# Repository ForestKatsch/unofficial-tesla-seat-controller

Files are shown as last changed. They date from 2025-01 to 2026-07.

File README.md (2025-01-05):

# (unofficial) Tesla seat controller

This project contains everything necessary to build an Arduino shield that reads the seat controls and drives the seat motors and ventilation fans.

## Why?

I built a simracing rig, and I discovered that used Tesla seats in good condition were around the same price as purpose-built simracing seats, and are much more comfortable to boot. The only problem is that they're electrically actuated and can't be manually adjusted.

## How?

- [**Instructions**](docs/instructions.md) (start here)
- [Switchpack reverse-engineering](docs/switchpack.md)

## Changelog

| date | change |
| --- | --- |
| 2025.01.04 | documentation consolidation and prep work for proto1 |
| 2024.08.18 | proto0 / validation |

## References and sources

- [Dan Simma's video](https://www.youtube.com/watch?v=71O_Hcep4HI) convinced me this project was doable
- [Tesla's Model S electrical schematics](https://service.tesla.com/docs/ModelS/ElectricalReference/prog-54/interactive/html/index.html?page=62&) made it easy to find out which wires went where
- [A Delta PWM fan, very similar to the ventilation fans in the seat](https://www.delta-fan.com/applications/automotive/BFB1012HD-04D4L.html)

## License

TODO

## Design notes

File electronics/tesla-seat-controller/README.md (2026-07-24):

# Standalone Tesla seat controller

STM32G0-based controller for four seat motors, two ventilation fans, and the seat switchpack. Input is a regulated 12 V Mean Well power supply; record the exact model before system testing.

## Design status

The schematic passes ERC and the automated MCU pin-contract tests. The DRV8262s use KiCad's official top-PowerPAD DDV footprint:

`Package_SO:HTSSOP-44_6.1x14mm_P0.635mm_TopEP4.14x7.01mm`

Do not substitute the bottom-PowerPAD DDW footprint. The DDV thermal pad is on top and requires a heatsink for sustained high current.

## PCB requirements

- Put each driver's 10 nF VM capacitors directly at its VM/PGND pin groups.
- Put the VCP, CPH/CPL, DVDD, and VCC capacitors directly at their pins.
- Give both drivers short, wide, comparable +12 V and ground paths; do not feed one through the other.
- Preserve top-side clearance and mounting support for both DRV8262 heatsinks.
- Route motor and input current paths for the fused 10 A system current plus short peaks.
- Clearly label motor outputs A/B/C/D on silkscreen. XT30 polarity marks are not fixed electrical polarity on reversible motor outputs.
- Run DRC and a separate PCB audit before fabrication.

## Firmware safety contract

- DRV8262 hardware current regulation is about 14.6 A nominal; expected motor stall current is about 8 A.
- Monitor IPROPI and stop a motor when an 8 A-class stall persists beyond the chosen timeout.
- Use PWM-mode `00` to coast when stopping. Ramp down before reversing; do not reverse directly at full duty. This limits regeneration into the Mean Well supply.
- Treat nFAULT as latched: clear a fault with the datasheet-defined nSLEEP reset sequence.
- Fan outputs are open-drain and inverted. The Delta reference fan expects approximately 100 Hz PWM and stops near both duty-cycle extremes; validate against the actual seat fans.

## Validation

Run from the repository root:

```sh
kicad-cli sch erc --severity-all --format report \
  --output /tmp/tesla-seat-controller-erc.rpt \
  electronics/tesla-seat-controller/tesla-seat-controller.kicad_sch

python3 tests/test_pinmap.py
```

Before powering motors, verify the exact Mean Well model can supply the expected startup current. During first hardware tests, scope +12 V while stopping and reversing a loaded motor; add a braking clamp only if the rail rises excessively or the supply trips.

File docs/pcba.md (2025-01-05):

# PCB Assembly

The seat controller PCB is designed in KiCAD version 8.

TODO

# BOM

| Part | Quantity |
| --- | --- |
| [3-pin 2.54mm male header](https://a.co/d/1hqvut4) | 2x |
| [4-pin 2.54mm male header ](https://a.co/d/1hqvut4) | 1x |
| [XT30 horizontal male through-hole](https://a.co/d/ecAGn9J)  | 1x |
| [2-pin 5mm screw terminal connector](https://a.co/d/eVUlu4d) | 1x |
| 0805 100nF capacitor | 3x |
| 0805 1k resistor | 3x |

You'll also need the four primary Arduino headers (no need for the two 2x3 pin headers). I recommend using [male pin headers](https://a.co/d/1hqvut4) mounted beneath the board to avoid physical contact with components on the motor driver shield.

| Part | Quantity |
| --- | --- |
| 10-pin 2.54mm male header | 1x |
| 8-pin 2.54mm male header  | 2x |
| 6-pin 2.54mm male header  | 1x |

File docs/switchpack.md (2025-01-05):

# Switchpack

The Tesla seat switchpack is the collection of controls on the side of the seat. There are three physical controls, connected via a four-wire harness.

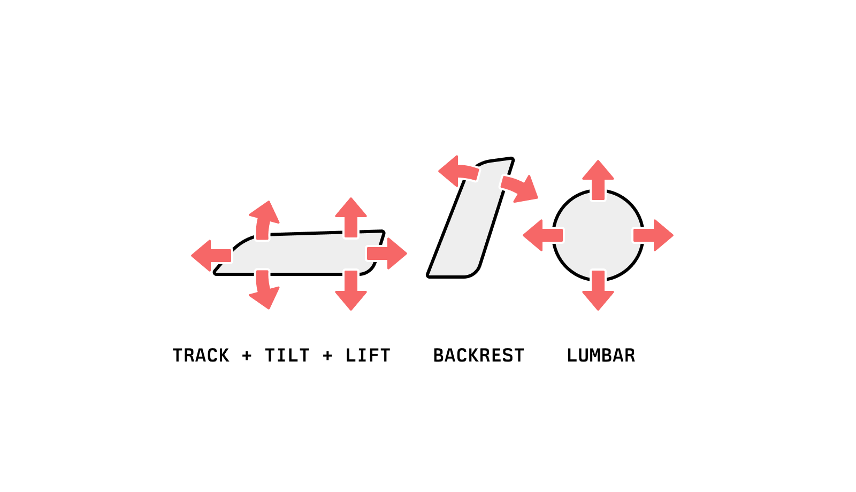
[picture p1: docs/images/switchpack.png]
The layout of the seat control switchpack, with a track + tilt + lift control at the front, a backrest lever behind it, and finally a four-way lumbar d-pad


Electrically, the switchpack interface has three signal wires and one ground line. When actuated, the switches assigned to each line vary the resistance of their corresponding wire.

| Numeric Index | Resistance Ω | Backrest + Track | Tilt + Lift | Lumbar |
| --- | ---: | --- | --- | --- |
| | 1.355 | | |
| #0 | 1.179 | Backrest Fore | Tilt Up | Fore |
| #1 | 0.774 | Backrest Aft | Tilt Down | Aft |
| #2 | 1.010 | Track Fore | Lift Up | Up |
| #3 | 0.677 | Track Aft | Lift Down | Down |

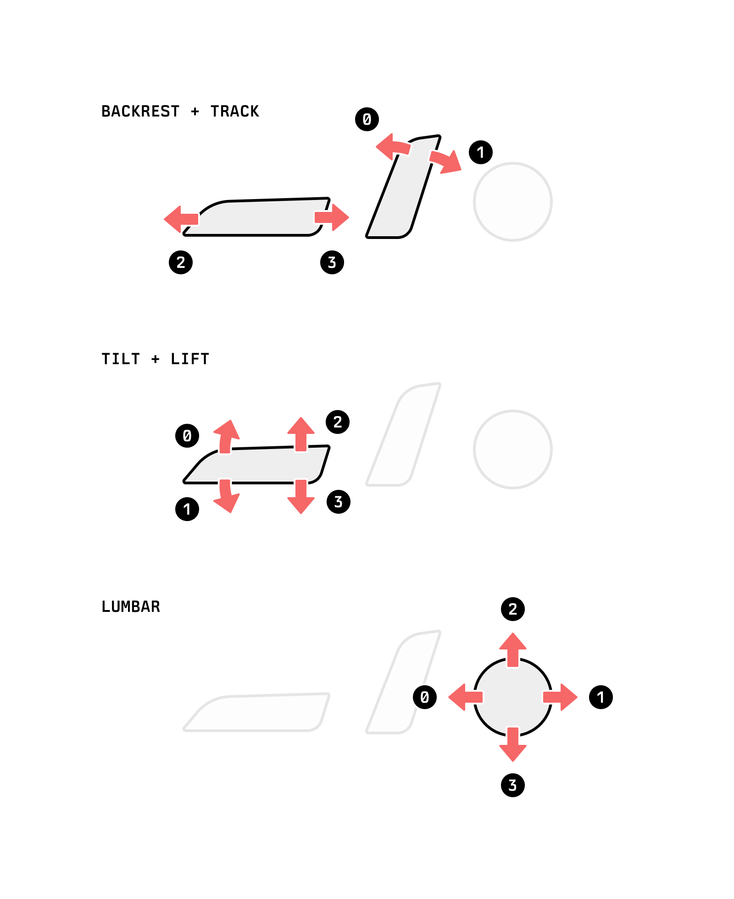
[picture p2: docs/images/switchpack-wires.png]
illustrated arrows of which controls use which wires


## Electronics

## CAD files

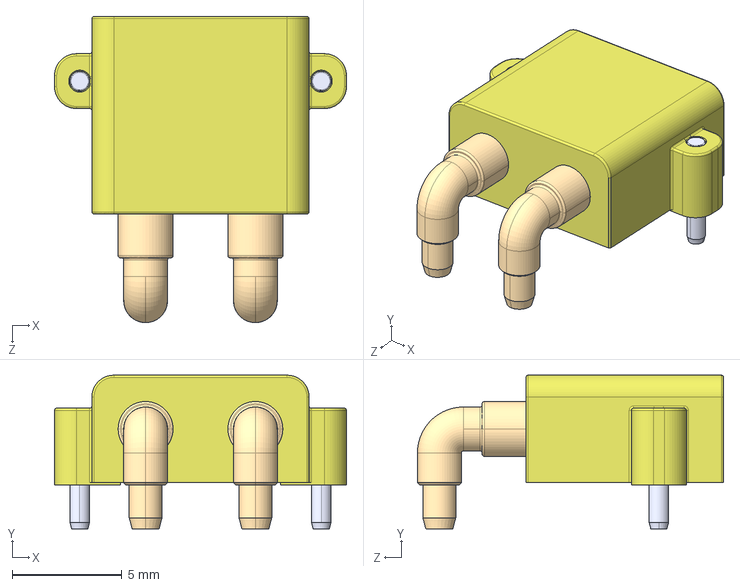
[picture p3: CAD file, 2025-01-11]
electronics/tesla-seat-controller-shield/parts/XT30PW-M--3DModel-STEP-269445.STEP
13.3 x 7.00 x 14.0 mm

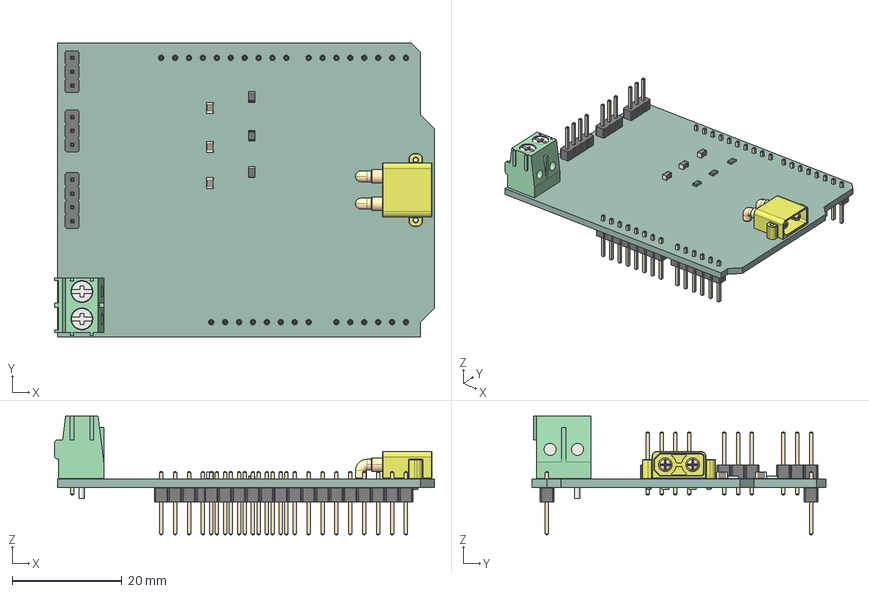
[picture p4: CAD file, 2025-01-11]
electronics/tesla-seat-controller-shield/tesla-seat-controller-shield.step
69.4 x 53.6 x 21.6 mm
XT30PW-M
C_0805_2012Metric x 3
PinHeader_1x04_P254mm_Vertical
PinHeader_1x03_P254mm_Vertical x 2
TerminalBlock_Phoenix_PT_15_2_50_H_1x02_P500mm_Horizontal
R_0805_2012Metric x 3
PinHeader_1x06_P254mm_Vertical
PinHeader_1x08_P254mm_Vertical x 2
PinHeader_1x10_P254mm_Vertical
tesla-seat-controller-shield_PCB

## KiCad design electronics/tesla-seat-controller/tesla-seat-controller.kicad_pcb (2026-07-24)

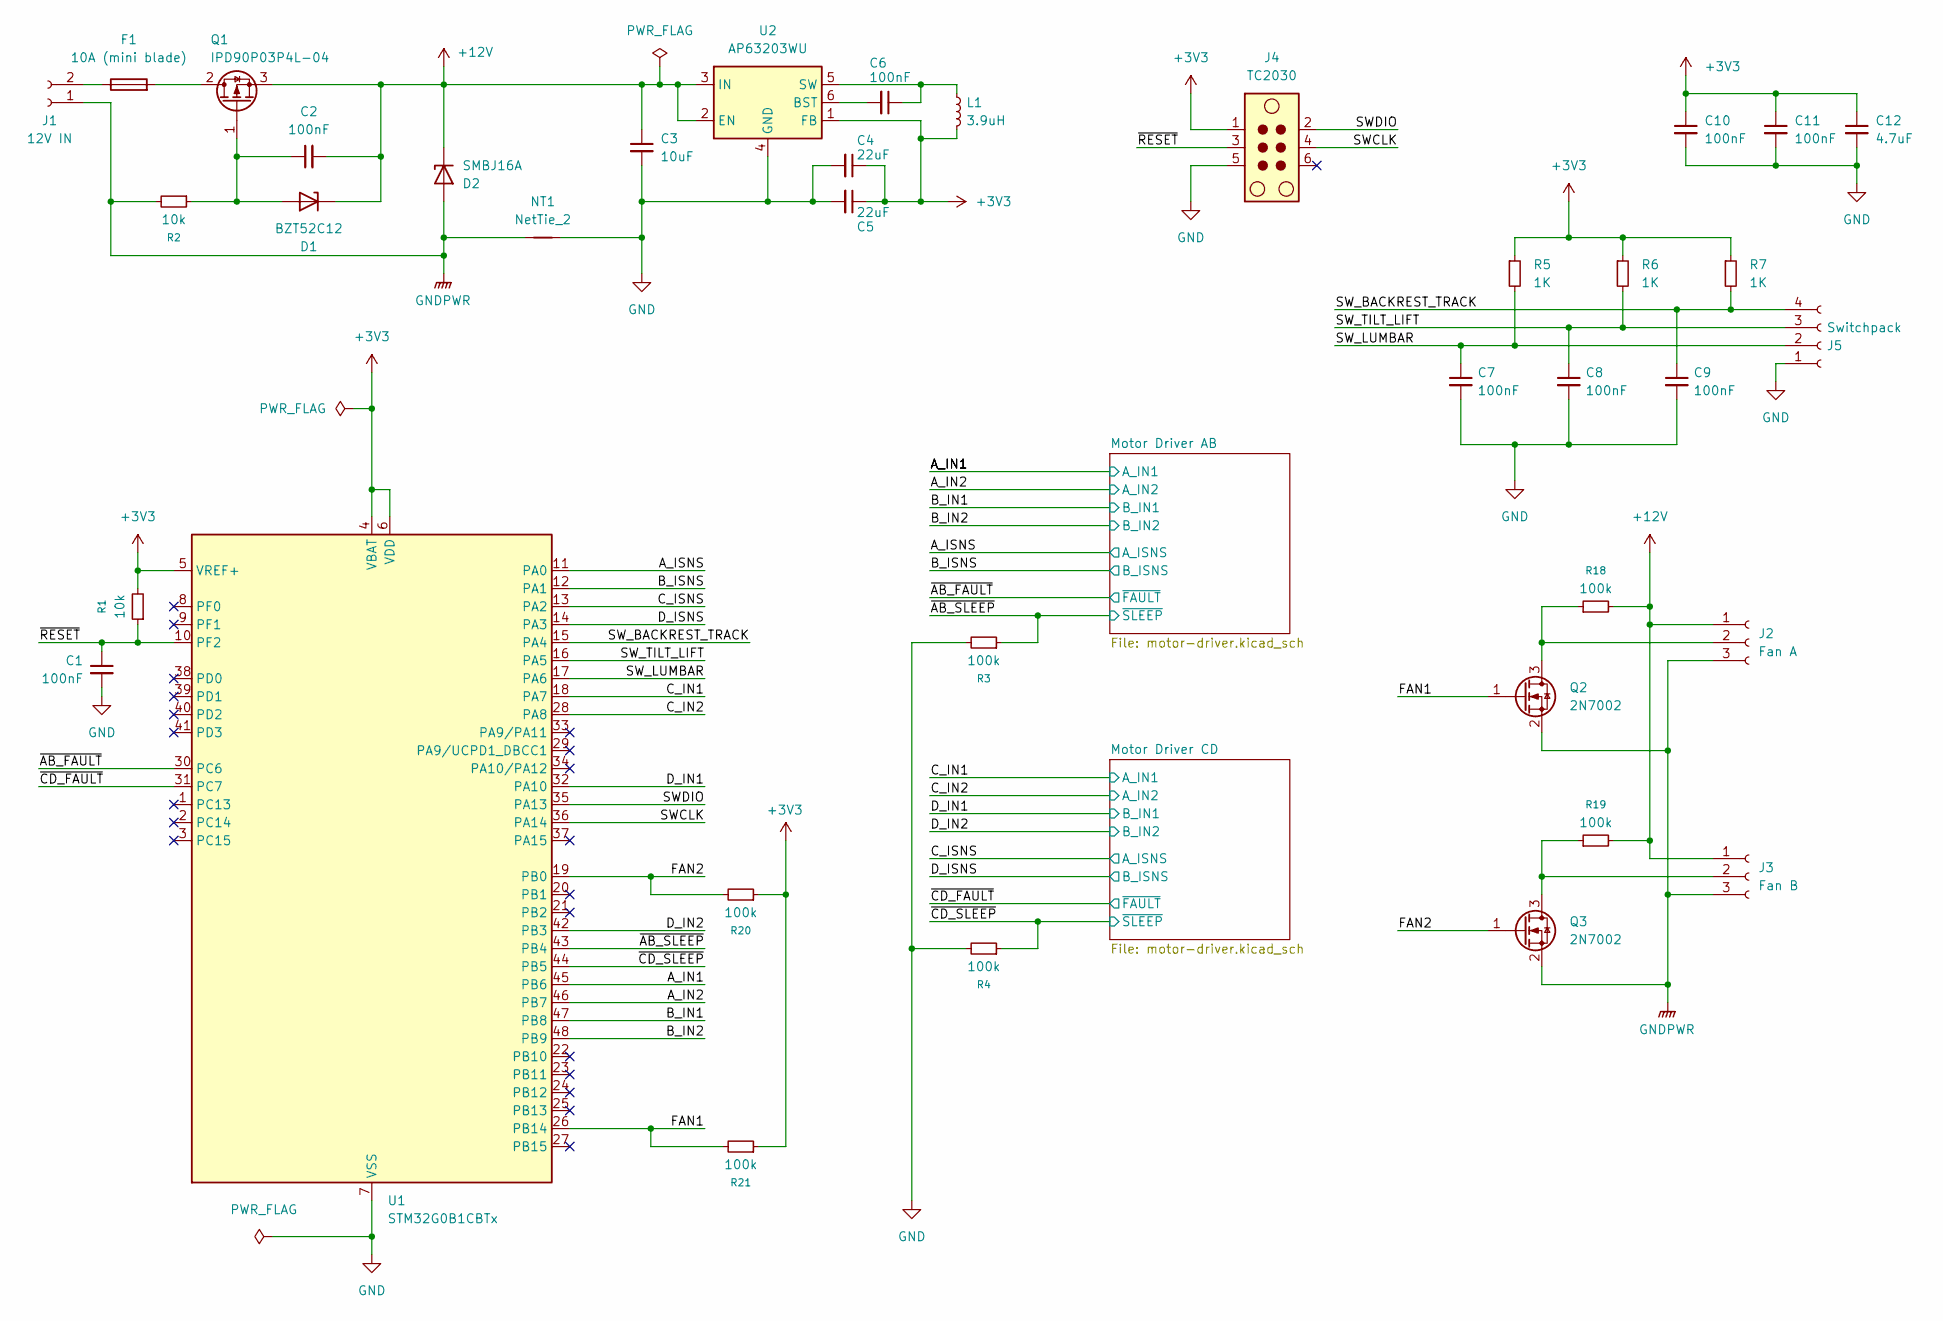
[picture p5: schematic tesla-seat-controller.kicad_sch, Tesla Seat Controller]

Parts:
C1, C2, C6, C7, C8, C9, C10, C11: 100nF; C_0805_2012Metric
C3: 10uF; C_1206_3216Metric
C4, C5: 22uF; C_1206_3216Metric
C12: 4.7uF; C_0805_2012Metric
D1: BZT52C12; D_SOD-123
D2: SMBJ16A; D_SMB
F1: 10A (mini blade); Fuseholder_Blade_Mini_Keystone_3568
J1: 12V IN; AMASS_XT30PW-M_1x02_P2.50mm_Horizontal
J2: Fan A; JST_XH_S3B-XH-A_1x03_P2.50mm_Horizontal
J3: Fan B; JST_XH_S3B-XH-A_1x03_P2.50mm_Horizontal
J4: TC2030; Tag-Connect_TC2030-IDC-NL_2x03_P1.27mm_Vertical
J5: Switchpack; JST_XH_S4B-XH-A_1x04_P2.50mm_Horizontal
L1: 3.9uH; L_Bourns_SRN6045TA
NT1: NetTie_2
Q1: IPD90P03P4L-04; TO-252-2
Q2, Q3: 2N7002; SOT-23
R1, R2: 10k; R_0805_2012Metric
R3, R4, R18, R19, R20, R21: 100k; R_0805_2012Metric
R5, R6, R7: 1K; R_0805_2012Metric
U1: STM32G0B1CBTx; LQFP-48_7x7mm_P0.5mm
U2: AP63203WU; TSOT-23-6

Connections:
+3V3: C4.1, C5.1, C10.1, C11.1, C12.1, J4.1, L1.2, R1.2, R5.1, R6.1, R7.1, R20.1, R21.1, U1.4 (VBAT), U1.5 (VREF+), U1.6 (VDD), U2.1 (FB); also elsewhere on the board
+12V: C2.2, C3.1, D1.1 (K), D2.1 (K), J2.1, J3.1, Q1.3 (S), R18.2, R19.2, U2.2 (EN), U2.3 (IN); also elsewhere on the board
/A_IN1: U1.45 (PB6); also elsewhere on the board
/A_IN2: U1.46 (PB7); also elsewhere on the board
/A_ISNS: U1.11 (PA0); also elsewhere on the board
/B_IN1: U1.47 (PB8); also elsewhere on the board
/B_IN2: U1.48 (PB9); also elsewhere on the board
/B_ISNS: U1.12 (PA1); also elsewhere on the board
/C_IN1: U1.18 (PA7); also elsewhere on the board
/C_IN2: U1.28 (PA8); also elsewhere on the board
/C_ISNS: U1.13 (PA2); also elsewhere on the board
/D_IN1: U1.32 (PA10); also elsewhere on the board
/D_IN2: U1.42 (PB3); also elsewhere on the board
/D_ISNS: U1.14 (PA3); also elsewhere on the board
/FAN1: Q2.1 (G), R21.2, U1.26 (PB14)
/FAN2: Q3.1 (G), R20.2, U1.19 (PB0)
/SWCLK: J4.4, U1.36 (PA14)
/SWDIO: J4.2, U1.35 (PA13)
/SW_BACKREST_TRACK: C9.1, J5.4, R7.2, U1.15 (PA4)
/SW_LUMBAR: C7.1, J5.2, R5.2, U1.17 (PA6)
/SW_TILT_LIFT: C8.1, J5.3, R6.2, U1.16 (PA5)
/~AB_FAULT: U1.30 (PC6); also elsewhere on the board
/~AB_SLEEP: R3.1, U1.43 (PB4); also elsewhere on the board
/~CD_FAULT: U1.31 (PC7); also elsewhere on the board
/~CD_SLEEP: R4.1, U1.44 (PB5); also elsewhere on the board
/~RESET: C1.1, J4.3, R1.1, U1.10 (PF2)
GND: C1.2, C3.2, C4.2, C5.2, C7.2, C8.2, C9.2, C10.2, C11.2, C12.2, J4.5, J5.1, NT1.2, R3.2, R4.2, U1.7 (VSS), U2.4 (GND); also elsewhere on the board
GNDPWR: D2.2 (A), J1.1, J2.3, J3.3, NT1.1, Q2.2 (S), Q3.2 (S), R2.2; also elsewhere on the board
unnamed: C2.1, D1.2 (A), Q1.1 (G), R2.1
unnamed: F1.1, J1.2
unnamed: J2.2, Q2.3 (D), R18.1
unnamed: J3.2, Q3.3 (D), R19.1
unnamed: F1.2, Q1.2 (D)
unnamed: C6.2, U2.6 (BST)
unnamed: C6.1, L1.1, U2.5 (SW)

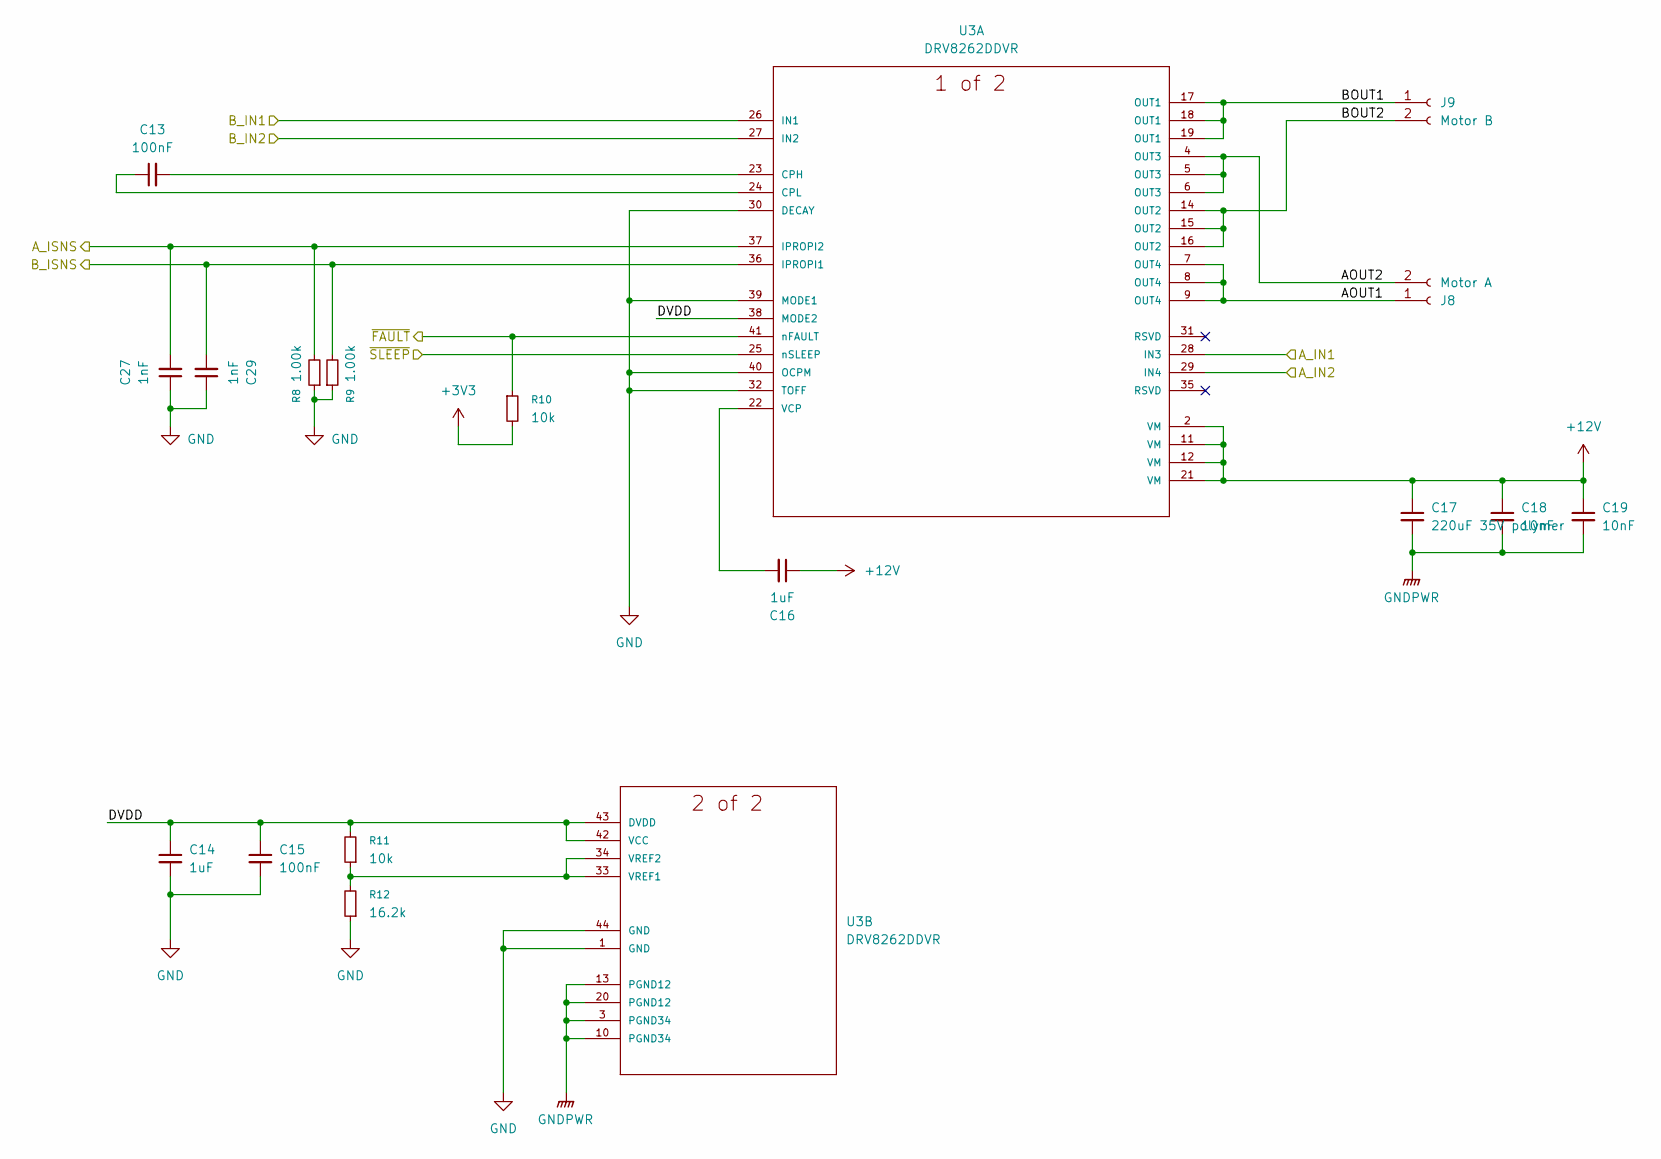
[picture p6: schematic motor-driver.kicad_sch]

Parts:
C13, C15: 100nF; C_0805_2012Metric
C14, C16: 1uF; C_0805_2012Metric
C17: 220uF 35V polymer; CP_Elec_10x10.5
C18, C19: 10nF; C_0805_2012Metric
C27, C29: 1nF; C_0805_2012Metric
J8: Motor A; AMASS_XT30PW-F_1x02_P2.50mm_Horizontal
J9: Motor B; AMASS_XT30PW-F_1x02_P2.50mm_Horizontal
R8, R9: 1.00k; R_0805_2012Metric
R10, R11: 10k; R_0805_2012Metric
R12: 16.2k; R_0805_2012Metric
U3: DRV8262DDVR; HTSSOP-44_6.1x14mm_P0.635mm_TopEP4.14x7.01mm; MANUFACTURER_PART_NUMBER DRV8262DDVR

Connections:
+3V3: R10.2; also elsewhere on the board
+12V: C16.1, C17.1, C18.1, C19.1, U3.2 (VM), U3.11 (VM), U3.12 (VM), U3.21 (VM); also elsewhere on the board
/A_IN1: U3.28 (IN3); also elsewhere on the board
/A_IN2: U3.29 (IN4); also elsewhere on the board
/A_ISNS: C27.2, R8.2, U3.37 (IPROPI2); also elsewhere on the board
/B_IN1: U3.26 (IN1); also elsewhere on the board
/B_IN2: U3.27 (IN2); also elsewhere on the board
/B_ISNS: C29.2, R9.2, U3.36 (IPROPI1); also elsewhere on the board
/Motor Driver AB/AOUT1: J8.1, U3.7 (OUT4), U3.8 (OUT4), U3.9 (OUT4)
/Motor Driver AB/AOUT2: J8.2, U3.4 (OUT3), U3.5 (OUT3), U3.6 (OUT3)
/Motor Driver AB/BOUT1: J9.1, U3.17 (OUT1), U3.18 (OUT1), U3.19 (OUT1)
/Motor Driver AB/BOUT2: J9.2, U3.14 (OUT2), U3.15 (OUT2), U3.16 (OUT2)
/Motor Driver AB/DVDD: C14.1, C15.1, R11.2, U3.38 (MODE2), U3.42 (VCC), U3.43 (DVDD)
/~AB_FAULT: R10.1, U3.41 (nFAULT); also elsewhere on the board
/~AB_SLEEP: U3.25 (nSLEEP); also elsewhere on the board
GND: C14.2, C15.2, C27.1, C29.1, R8.1, R9.1, R12.1, U3.1 (GND), U3.30 (DECAY), U3.32 (TOFF), U3.39 (MODE1), U3.40 (OCPM), U3.44 (GND); also elsewhere on the board
GNDPWR: C17.2, C18.2, C19.2, U3.3 (PGND34), U3.10 (PGND34), U3.13 (PGND12), U3.20 (PGND12); also elsewhere on the board
unnamed: C13.2, U3.23 (CPH)
unnamed: C13.1, U3.24 (CPL)
unnamed: C16.2, U3.22 (VCP)
unnamed: R11.1, R12.2, U3.33 (VREF1), U3.34 (VREF2)

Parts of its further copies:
C20, C22: 100nF; C_0805_2012Metric
C21, C23: 1uF; C_0805_2012Metric
C24: 220uF 35V polymer; CP_Elec_10x10.5
C25, C26: 10nF; C_0805_2012Metric
C28, C30: 1nF; C_0805_2012Metric
J6: Motor A; AMASS_XT30PW-F_1x02_P2.50mm_Horizontal
J7: Motor B; AMASS_XT30PW-F_1x02_P2.50mm_Horizontal
R13, R14: 1.00k; R_0805_2012Metric
R15, R16: 10k; R_0805_2012Metric
R17: 16.2k; R_0805_2012Metric
U4: DRV8262DDVR; HTSSOP-44_6.1x14mm_P0.635mm_TopEP4.14x7.01mm; MANUFACTURER_PART_NUMBER DRV8262DDVR

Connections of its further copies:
+3V3: R15.2; also elsewhere on the board
+12V: C23.1, C24.1, C25.1, C26.1, U4.2 (VM), U4.11 (VM), U4.12 (VM), U4.21 (VM); also elsewhere on the board
/C_IN1: U4.28 (IN3); also elsewhere on the board
/C_IN2: U4.29 (IN4); also elsewhere on the board
/C_ISNS: C28.2, R13.2, U4.37 (IPROPI2); also elsewhere on the board
/D_IN1: U4.26 (IN1); also elsewhere on the board
/D_IN2: U4.27 (IN2); also elsewhere on the board
/D_ISNS: C30.2, R14.2, U4.36 (IPROPI1); also elsewhere on the board
/Motor Driver CD/AOUT1: J6.1, U4.7 (OUT4), U4.8 (OUT4), U4.9 (OUT4)
/Motor Driver CD/AOUT2: J6.2, U4.4 (OUT3), U4.5 (OUT3), U4.6 (OUT3)
/Motor Driver CD/BOUT1: J7.1, U4.17 (OUT1), U4.18 (OUT1), U4.19 (OUT1)
/Motor Driver CD/BOUT2: J7.2, U4.14 (OUT2), U4.15 (OUT2), U4.16 (OUT2)
/Motor Driver CD/DVDD: C21.1, C22.1, R16.2, U4.38 (MODE2), U4.42 (VCC), U4.43 (DVDD)
/~CD_FAULT: R15.1, U4.41 (nFAULT); also elsewhere on the board
/~CD_SLEEP: U4.25 (nSLEEP); also elsewhere on the board
GND: C21.2, C22.2, C28.1, C30.1, R13.1, R14.1, R17.1, U4.1 (GND), U4.30 (DECAY), U4.32 (TOFF), U4.39 (MODE1), U4.40 (OCPM), U4.44 (GND); also elsewhere on the board
GNDPWR: C24.2, C25.2, C26.2, U4.3 (PGND34), U4.10 (PGND34), U4.13 (PGND12), U4.20 (PGND12); also elsewhere on the board
unnamed: C20.2, U4.23 (CPH)
unnamed: C20.1, U4.24 (CPL)
unnamed: C23.2, U4.22 (VCP)
unnamed: R16.1, R17.2, U4.33 (VREF1), U4.34 (VREF2)

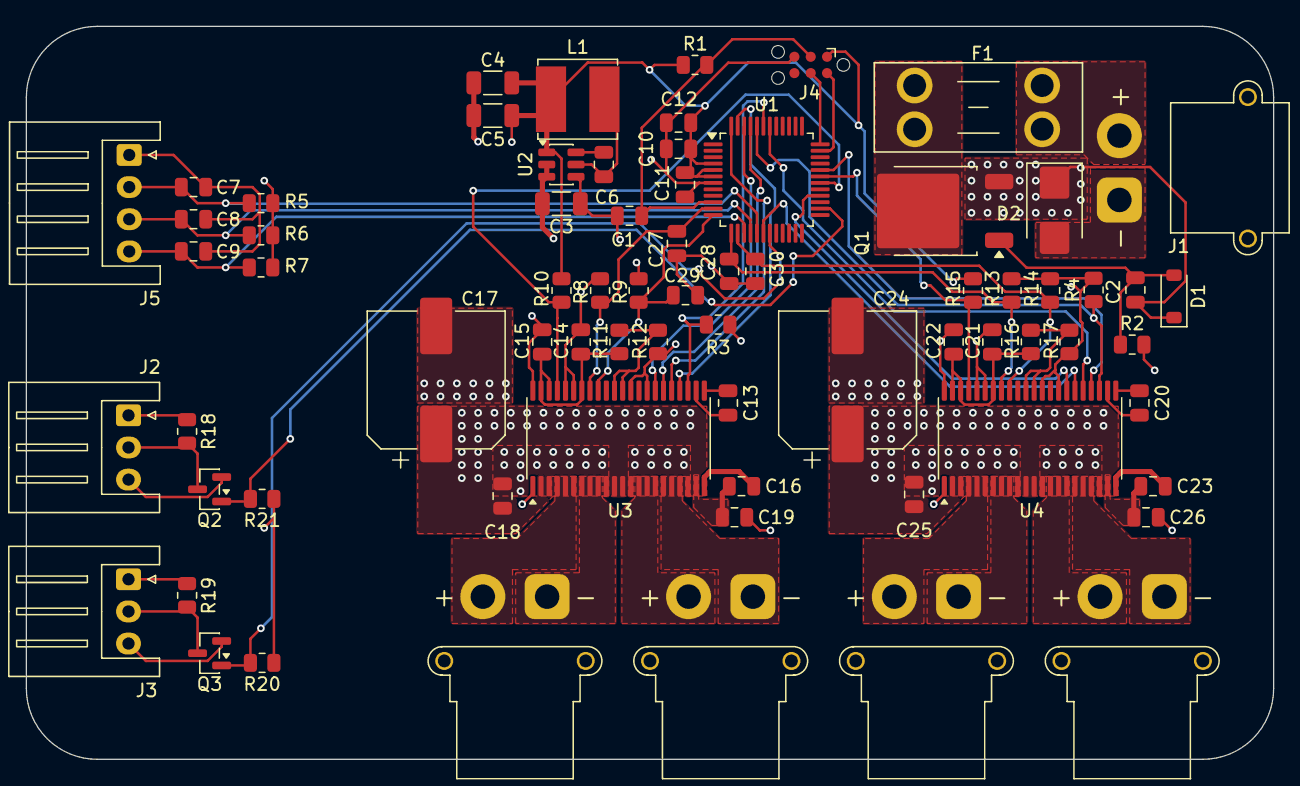
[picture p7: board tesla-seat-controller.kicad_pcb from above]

Board: 4 copper layers, 97.0 x 57.0 mm, 71 parts (0 on the bottom side), 53 nets.

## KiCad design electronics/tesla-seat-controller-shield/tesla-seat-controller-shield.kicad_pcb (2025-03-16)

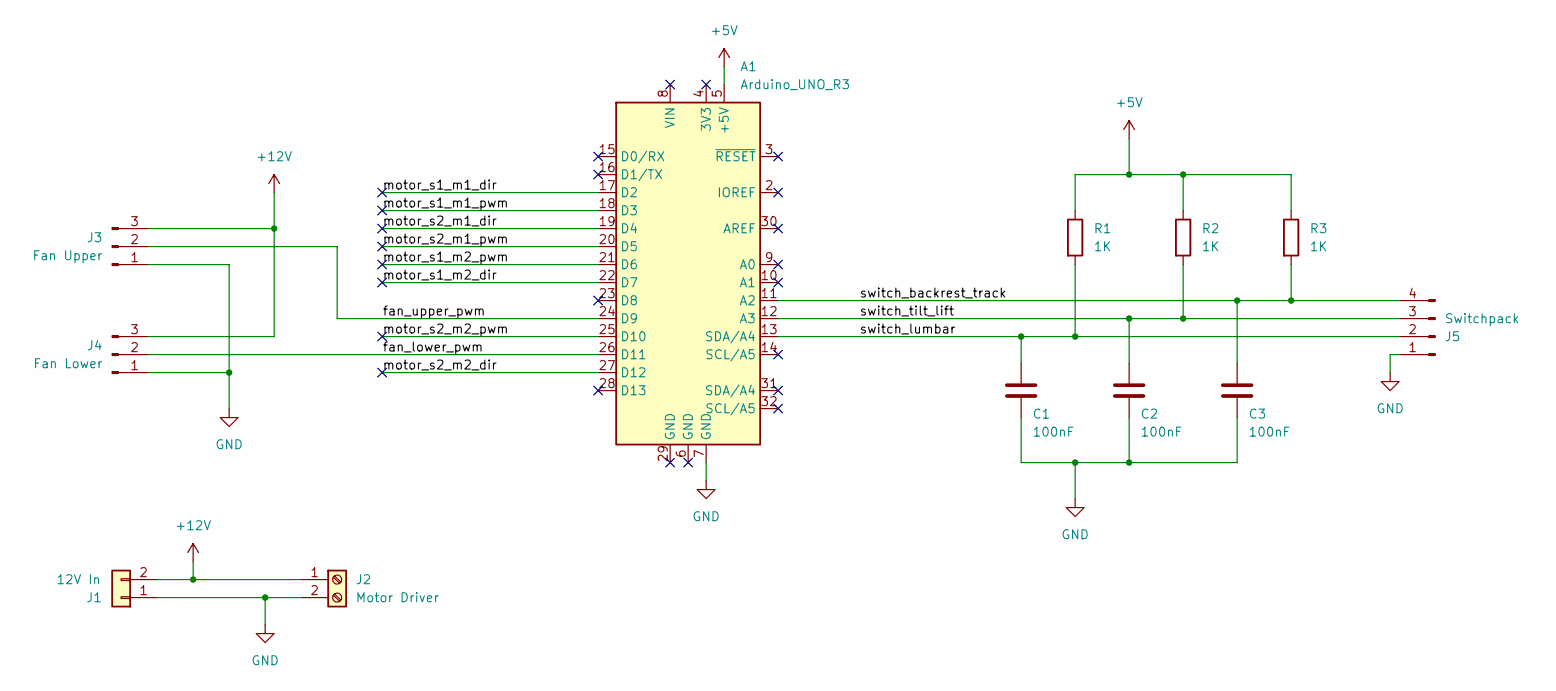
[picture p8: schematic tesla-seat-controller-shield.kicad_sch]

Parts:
A1: Arduino_UNO_R3
C1, C2, C3: 100nF; C_0805_2012Metric_Pad1.18x1.45mm_HandSolder
J1: 12V In; AMASS_XT30PW-M_1x02_P2.50mm_Horizontal
J2: Motor Driver; TerminalBlock_bornier-2_P5.08mm
J3: Fan Upper; PinHeader_1x03_P2.54mm_Vertical
J4: Fan Lower; PinHeader_1x03_P2.54mm_Vertical
J5: Switchpack; PinHeader_1x04_P2.54mm_Vertical
R1, R2, R3: 1K; R_0805_2012Metric_Pad1.20x1.40mm_HandSolder

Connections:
+5V: A1.5 (+5V), R1.1, R2.1, R3.1
+12V: J1.2, J2.1, J3.3, J4.3
/fan_lower_pwm: A1.26 (D11), J4.2
/fan_upper_pwm: A1.24 (D9), J3.2
/motor_s1_m1_dir: A1.17 (D2)
/motor_s1_m1_pwm: A1.18 (D3)
/motor_s1_m2_dir: A1.22 (D7)
/motor_s1_m2_pwm: A1.21 (D6)
/motor_s2_m1_dir: A1.19 (D4)
/motor_s2_m1_pwm: A1.20 (D5)
/motor_s2_m2_dir: A1.27 (D12)
/motor_s2_m2_pwm: A1.25 (D10)
/switch_backrest_track: A1.11 (A2), C3.1, J5.4, R3.2
/switch_lumbar: A1.13 (SDA/A4), C1.1, J5.2, R1.2
/switch_tilt_lift: A1.12 (A3), C2.1, J5.3, R2.2
GND: A1.7 (GND), C1.2, C2.2, C3.2, J1.1, J2.2, J3.1, J4.1, J5.1

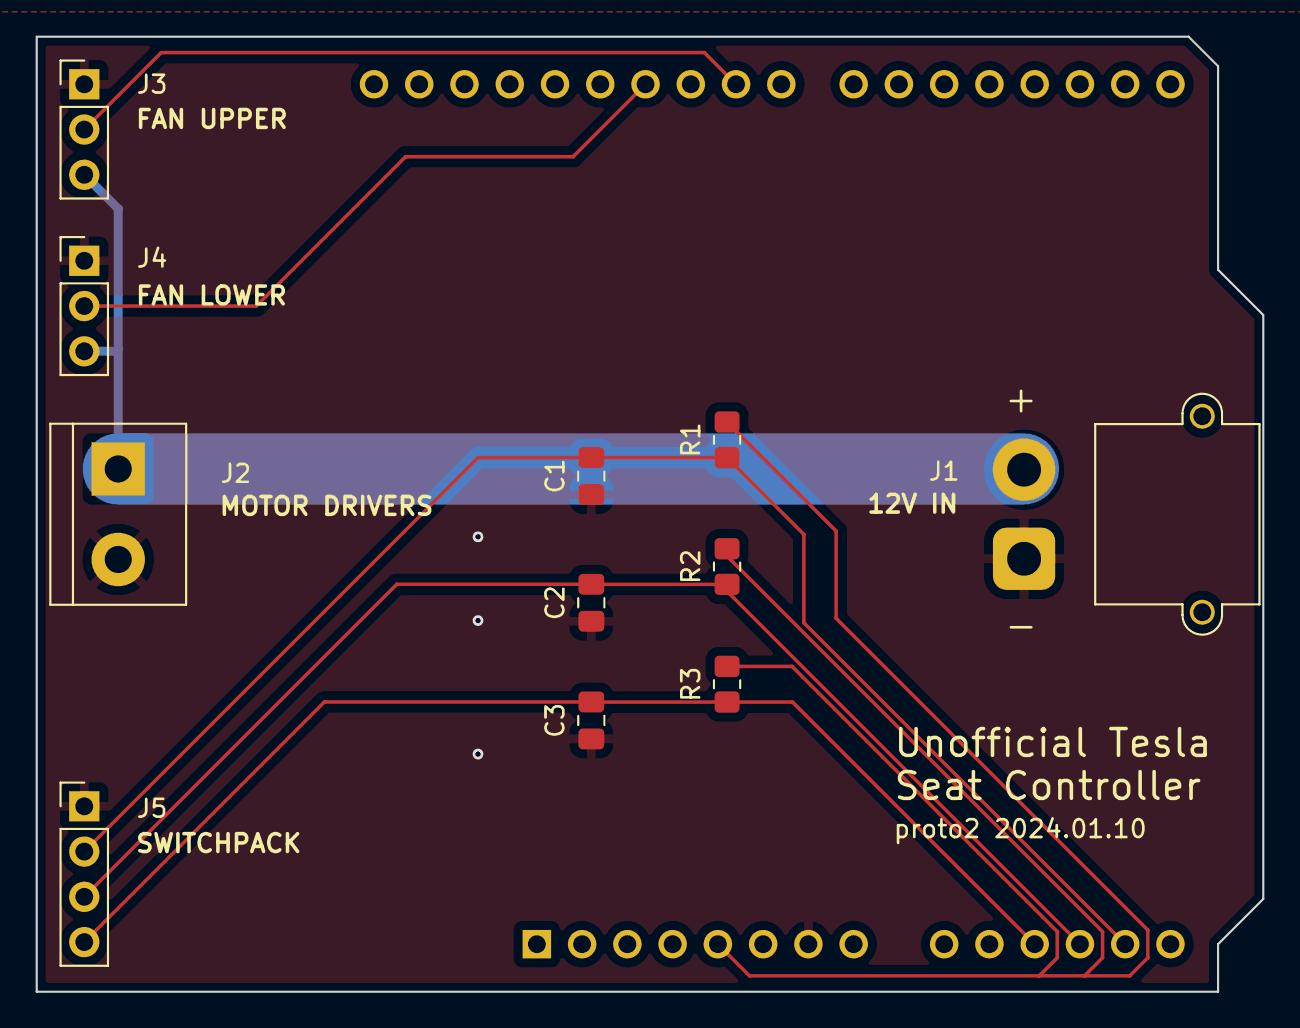
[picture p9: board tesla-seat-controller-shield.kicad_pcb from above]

Board: 11 copper layers, 68.8 x 53.6 mm, 12 parts (1 on the bottom side), 8 nets.

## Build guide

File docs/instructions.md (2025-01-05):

# Instructions

> [!NOTE]
> This project was built around a 2022 Model S (refresh) seat. While I have reason to believe this project will almost certainly work with all modern Tesla 12V seats (excluding Cybertruck), I cannot test or guarantee compatibility.

In addition to the parts required for the [PCB assembly](docs/pcba.md), you will also need:

- An Arduino Uno
- 2x [Cytron Arduino motor drivers](https://www.cytron.io/p-10amp-7v-30v-dc-motor-driver-shield-for-arduino-2-channels) (part number SHIELD-MDD10A; [datasheet](https://docs.google.com/document/d/1QHlQbs6f5fY_BMBs3hJRg1QLFe4yqy4nyH3mBavZ2-0/view))

You'll need some basic electronic tools to assemble the board and splice the seat wires.

## Seat controller shield

Once you have a PCB on hand, you can [proceed to assemble it](docs/pcba.md).

## Motor driver shield

You'll need to cut the 5V Output Solder Jumper on **only one of** the shields, to prevent both motor driver shields from attempting to drive the Vin shield pin. See the [datasheet](https://docs.google.com/document/d/1QHlQbs6f5fY_BMBs3hJRg1QLFe4yqy4nyH3mBavZ2-0/view) for more detail.

## Housing and cable management

TODO

## Mounting

I designed and 3D-printed standoffs that elevate my Model S (refresh) seat track rails above the built-in alignment pins. These will likely not work with other seats.

TODO

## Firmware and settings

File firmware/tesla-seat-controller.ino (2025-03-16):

#define DEBUG (1)

#include "motor.h"
#include "switch.h"
#include "fan.h"

MotorDriver motor_backrest(3, 2);
MotorDriver motor_lift(10, 12);
MotorDriver motor_track(9, 8);
MotorDriver motor_tilt(11, 13);

SwitchPackWire track_backrest(A2);
SwitchPackWire lift_tilt(A3);
SwitchPackWire lumbar(A4);

FanDriver fan_lower(11);
FanDriver fan_upper(12);

// Fan global speed control

#define FAN_SPEED_OFF (0)
#define FAN_SPEED_LOW (1)
#define FAN_SPEED_MED (2)
#define FAN_SPEED_HIGH (3)

#define FAN_SPEED_MIN FAN_SPEED_OFF
#define FAN_SPEED_MAX FAN_SPEED_HIGH

int8_t fan_setting = FAN_SPEED_OFF;

void fanSpeedOffset(int8_t by) {
  // Bounds check.
  if (fan_setting == FAN_SPEED_MIN && by < 0) {
    return;
  } else if (fan_setting == FAN_SPEED_MAX && by > 0) {
    return;
  }

  fan_setting += by;
}

const uint8_t fan_pwm[FAN_SPEED_MAX + 1] = {0, 72, 128, 255};

// Helpers

void readSwitches() {
  lift_tilt.read();
  track_backrest.read();
  lumbar.read();
}

void runMotors() {
 motor_backrest.setSpeed(track_backrest.pressed & SWITCH_BACKREST_FORWARD ? 255
                         : track_backrest.pressed & SWITCH_BACKREST_REARWARD
                             ? -255
                             : 0);
 motor_tilt.setSpeed(lift_tilt.pressed & SWITCH_TILT_DOWN ? 255
                     : lift_tilt.pressed & SWITCH_TILT_UP ? -255
                                                          : 0);
 motor_lift.setSpeed(lift_tilt.pressed & SWITCH_LIFT_DOWN ? 255
                     : lift_tilt.pressed & SWITCH_LIFT_UP ? -255
                                                          : 0);
 motor_track.setSpeed(track_backrest.pressed & SWITCH_TRACK_FORE  ? 255
                      : track_backrest.pressed & SWITCH_TRACK_AFT ? -255
                                                                  : 0);
}

void runFans() {
  fan_lower.setSpeed(fan_pwm[fan_setting]);
  fan_upper.setSpeed(fan_pwm[fan_setting]);
}

// Setup + loop

void setup() {
#if DEBUG
  delay(500);
  Serial.begin(9600);

  Serial.print("Logs working");
  Serial.println();
#endif
}

// the loop function runs over and over again forever
void loop() {
  delay(10);

  readSwitches();
  runMotors();

  if (lumbar_up.just_released) {
    fanSpeedOffset(1);
  } else if(lumbar_down.just_released) {
    fanSpeedOffset(-1);
  }

  runFans();
}

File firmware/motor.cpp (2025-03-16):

#include "motor.h"

#include <Arduino.h>

MotorDriver::MotorDriver(uint8_t pwm_pin, uint8_t dir_pin) {
  this->dir = dir_pin;
  this->pwm = pwm_pin;

  pinMode(dir, OUTPUT);
  pinMode(pwm, OUTPUT);
  setSpeed(0);
}

/** Runs a motor at the provided speed until commanded to stop.
 * Speed should be between -255 and 255.
 */
void MotorDriver::setSpeed(int16_t speed) {
  if (speed > 255) {
    speed = 255;
  } else if (speed < -255) {
    speed = -255;
  }

  if (speed != 0) {
    Serial.print("motor commanded");
    Serial.println();
  }

  if (speed >= 0) {
    digitalWrite(dir, LOW);
    analogWrite(pwm, speed);
  } else {
    digitalWrite(dir, HIGH);
    analogWrite(pwm, -speed);
  }
}

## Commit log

2025-01-05 Update switchpack docs
2025-01-05 Add KiCAD PCB
    [tesla-seat-controller-shield.kicad_pcb, tesla-seat-controller-shield.kicad_sch]
2025-01-05 Mirror Arduino shield and update some documentation paths
    [tesla-seat-controller-shield.kicad_pcb, tesla-seat-controller-shield.kicad_sch]
2025-01-05 Replace silly vertical mirror with flip + 180
    [tesla-seat-controller-shield.kicad_pcb]
2025-01-10 Add teardrops
    [tesla-seat-controller-shield.kicad_pcb]
2025-01-11 Add 3D models and make board updates to match shield layout
    [XT30PW-M--3DModel-STEP-269445.STEP, tesla-seat-controller-shield.kicad_pcb, tesla-seat-controller-shield.kicad_sch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]
2025-01-13 Update part positions and remove 12v Vin
    [tesla-seat-controller-shield.kicad_pcb, tesla-seat-controller-shield.kicad_sch]
2025-02-01 Upgrade to KiCAD 9.0.0 rc2
    [tesla-seat-controller-shield.kicad_pcb]
2025-03-16 Reshuffle pins
    [tesla-seat-controller-shield.kicad_pcb, tesla-seat-controller-shield.kicad_sch]
2025-03-16 Add draft fan support
2025-05-17 kicad 9
    [tesla-seat-controller.kicad_pcb, tesla-seat-controller.kicad_sch]
2026-06-18 Add project KiCad library with DRV8262 motor driver
    Vendor symbol + footprint + STEP model (SnapEDA/TI export) for the
    DRV8262DDWR dual H-bridge motor driver, plus project sym-lib-table /
    fp-lib-table so it resolves via ${KIPRJMOD} for anyone who clones.
    Linked the STEP into the footprint and pointed the symbol's footprint
    field at the project nickname.
2026-06-18 update schematic for 2354
    [tesla-seat-controller.kicad_sch]
2026-06-19 Add standalone seat-controller schematic: RP2354 + dual DRV8262 drivers
    Build out the non-shield board around an RP2354B with two DRV8262
    dual-H-bridge motor drivers (4 seat motors total), using one reusable
    motor-driver hierarchical sheet instanced twice.
    - motor-driver.kicad_sch: DRV8262 in dual-H-bridge PWM mode (MODE1=GND,
    MODE2=DVDD), charge pump, VREF divider (~3.3V), IPROPI sense (3.09k,
    ~5A trip), per-motor 2-pin output connectors. Verified via netlist.
    - Root: RP2354B core regulator (3.3uH + 4.7uF, 33ohm/4.7uF AVDD filter),
    12MHz crystal, USB-C, SWD, BOOTSEL, AP63203 3.3V buck, RUN reset RC.
    Values cross-checked against the RP2350 hardware design guide.
    - Clean up the SnapE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
    [motor-driver.kicad_sch, tesla-seat-controller.kicad_sch]
2026-06-20 Finish out protection + fan
    [tesla-seat-controller.kicad_sch]
2026-07-18 Audit fixes, DRV8262 DDV swap, 14.6A ITRIP, pin-contract tests
    Schematic (all verified against datasheets, ERC clean):
    - Flip D2 SMBJ16A TVS (was installed backwards, would short the 12V rail)
    - C12 4.7nF -> 4.7uF (STM32 VDD bulk decoupling per DS13560)
    - U2 now a proper Regulator_Switching:AP63203WU (symbol/value/lib_id were
    inconsistent AP63205WU with overridden value)
    - D1 BZX84C15 -> BZX84C12 (Q1 IPD90P03P4L-04 VGS max is +5/-16V)
    - Swap DRV8262DDWR -> DRV8262DDVR (top thermal pad for heatsink, 16A peak /
    10A RMS per output in dual H-bridge). Symbol pins renumbered in place per
    datasheet Table 4-1 so all wiring is untouched; EPAD pin/pad and its stub
    wires removed (DDV pad is hea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
    [motor-driver.kicad_sch, tesla-seat-controller.kicad_sch]
2026-07-18 Footprint/BOM pass: 0805 baseline for DIY reflow, side-exit connectors
    - All passives 0805 (standard reflow pads, HandSolder variants normalized);
    exceptions: C3/C4/C5 in 1206 (10uF 50V, 22uF), C17/C24 upgraded
    100uF -> 220uF 35V polymer hybrid (CP_Elec 10x10.5) for the ~14.6A
    chopping level
    - D1 BZX84C12 (SOT-23) -> BZT52C12 (SOD-123): same 12V zener, 2-pad
    package matches the 2-pin symbol and is easier to assemble
    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
    [motor-driver.kicad_sch, tesla-seat-controller.kicad_sch]
2026-07-18 Add schematic title blocks
    [motor-driver.kicad_sch, tesla-seat-controller.kicad_sch]
2026-07-24 Complete PCB layout: 4-layer, GND/GNDPWR split, 3D models, DRC clean
    - 4-layer stackup: In1 split ground planes (GND logic / GNDPWR power,
    joined by net tie NT1 at J1), In2 partial +12V plane
    - Schematic: GNDPWR net for motor/power return paths (PGND pins, VM
    bypass + bulk caps, battery return, TVS, fans); logic/analog stays
    on GND (IPROPI sense, VREF, DVDD, MCU, buck)
    - Both DRV8262 channels placed and routed (multichannel clone), solid
    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
    [motor-driver.kicad_sch, tesla-seat-controller.kicad_pcb, tesla-seat-controller.kicad_sch]

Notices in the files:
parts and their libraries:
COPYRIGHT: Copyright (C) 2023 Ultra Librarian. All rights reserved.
